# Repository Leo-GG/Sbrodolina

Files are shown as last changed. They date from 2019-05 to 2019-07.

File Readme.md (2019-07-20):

# Sbrodolina

Sbrodolina is a Bioprinter I designed as a consequence of finding myself in possesion of a 3D printer and too much free time.
I started this project with little knowledge about 3D printing, with the intention to educate myself, have fun taking up the challenge of designing a printer from scratch and eventually rejoice seeing it spill some liquids.
She is not the prettiest but I love her all the same.

See it in action in all its glory here: [Sbrodolina spilling water around](https://youtu.be/jMWw5LMnzZg).

Printer Sbrodolina in its current status

Front view Sbrodolina in its current status

## Current status (20/07/2019)

* [First test completed](https://youtu.be/jMWw5LMnzZg)! Extruded water on a piece of cardboard, great success!
* Next goal is to print some more interesting material, but who know when I'll have the time :/
* Few temporary solutions need to be reworked:
  * Endstops are currently held by cable ties. This hurts my eyes every time I see it
  * The syringe pump should be mounted somewhere on the printer
  * Same for the power supply and the Arduino, it is quite messy as it is now
  * The design of the syringe holder on the pump is plainly horrible. I intend to amend this
  * It needs a decent plate to print on

## Design

I designed the printer using aluminium profiles and lead screws on all axis. The idea was to get a robust design. And plenty of wheels and screws everywhere.
Since it is meant to extrude liquids rather than filament, it uses a pipette tip connected to a syringe pump. The syring pump was also 3D printed and has even more design flaws than the body of the printer.

## Control

The printer is controlled like any regular open source 3D printer: I used an Arduino board with a RAMPS shield to control all the motors and endstops. 
I used the MARLIN firmware on the Arduino side and for the time being I use Pronterface to control the printer manually.

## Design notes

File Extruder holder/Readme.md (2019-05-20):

# Extruder holder

This is just a piece meant to hold a pipette or a syring tip. 100% sure this is the ugliest part of the printer. It uses 2 3mm screws with nuts locked in the plastic part to hold the pipette tip in place/
Extruder holder Pipette tip holder

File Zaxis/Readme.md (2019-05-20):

# Z axis

This axis consists of two motors attached to the frame with the same motor mount used in the Y axis. 
Each motor drives a 8mm leadscrew that moves the carriers. The carriers on the motor side are the same as in the Y axis. 
On the front side (opposite to the motors) the carriers are just a flat piece with four holes for 5mm screw nuts (to hold the two sides together) and four holes for 5mm screws to hold the X axis mount. 
Zaxis Z axis motor
The X axis mount is a single piece on each side. I first tried using 4 separated angle pieces, but it was way too wobbly. The current design is not too terrible, so it might stay as it is.

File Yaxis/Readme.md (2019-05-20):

# Y axis

This is the first axis I designed after I managed to make the syringe pump. It consist of a motor mounted on a 20x40 V-shaped aluminum piece and a "carrier" with a leadscrew nut and 4 bearings to move along the frame.
Y axis

The part holding the leadscrew nut are fixed with 3mm screws that are inserted in the corresponding 3mm nuts inserted in the main pieces of the carrier. I was expecting this piece to break apart as soon as the motor started to rotate, but instead they seem to be holding quite well :)

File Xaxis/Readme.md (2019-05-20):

# X axis

This axis consist of a 20x20 V-shaped aluminum frame mounted on the two Z-axis carriers.
axis X axis

The motor is mounted on the 20x20 piece with 2 3D-printed angles that hold the same motor mount used in in all axis. These angles turned out to be rather fragile, I broke them twice when I screwed them too hard against the 20x20 piece.
The carrier for the "extruder" is modified with respect to the other axis to fit the 20mm aluminum piece (the rest are 40mm) and has three 5mm screw holes with holes for the nuts on the back to mount the pipette holder.
axisMotor X axis motor

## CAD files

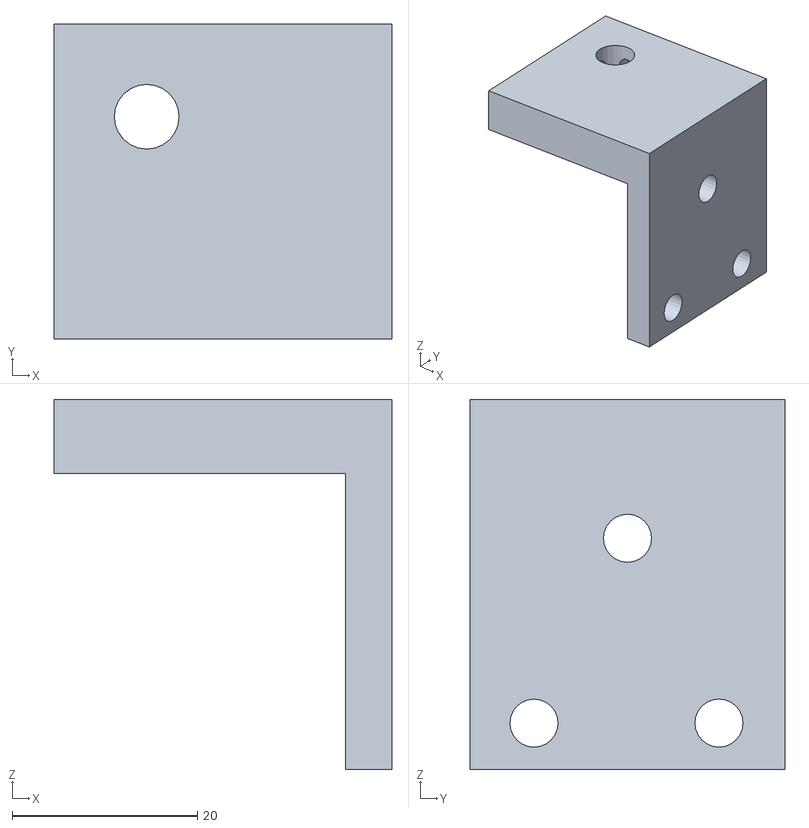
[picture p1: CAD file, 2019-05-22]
Extruder holder/tip_holderDONOTJUDGEMEFORTHIS.stl
36.5 x 34.0 x 40.0

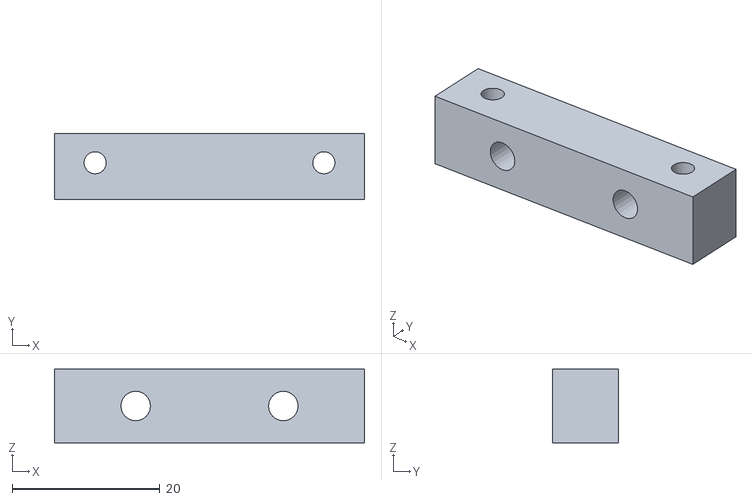
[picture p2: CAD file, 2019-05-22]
Xaxis/motor_mount.stl
42.0 x 9.00 x 10.00

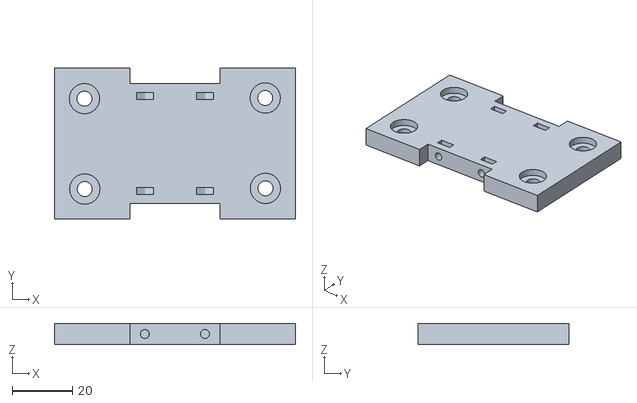
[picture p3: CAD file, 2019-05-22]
Yaxis/carrier_body.stl
80.0 x 50.0 x 7.00

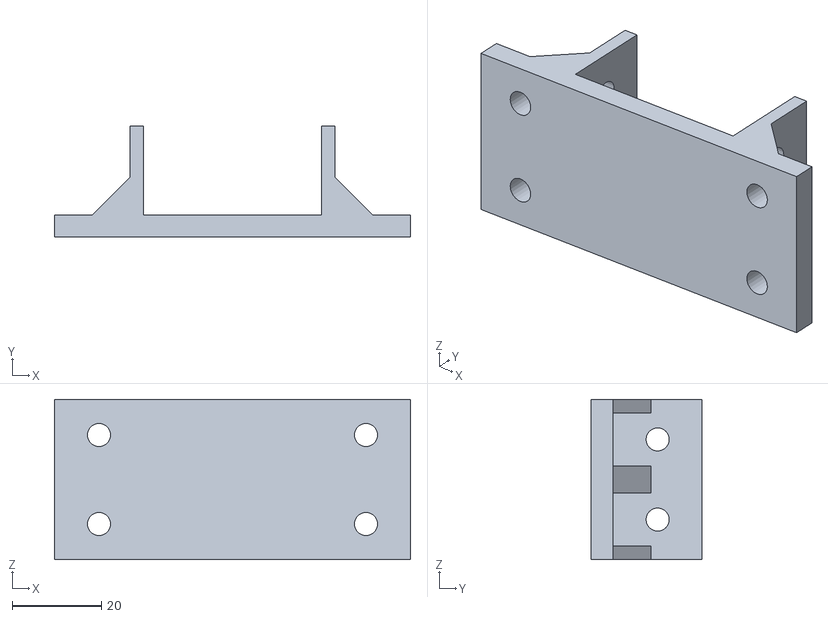
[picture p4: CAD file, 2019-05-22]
Zaxis/Xaxis_rail_mount.stl
80.0 x 25.0 x 36.0

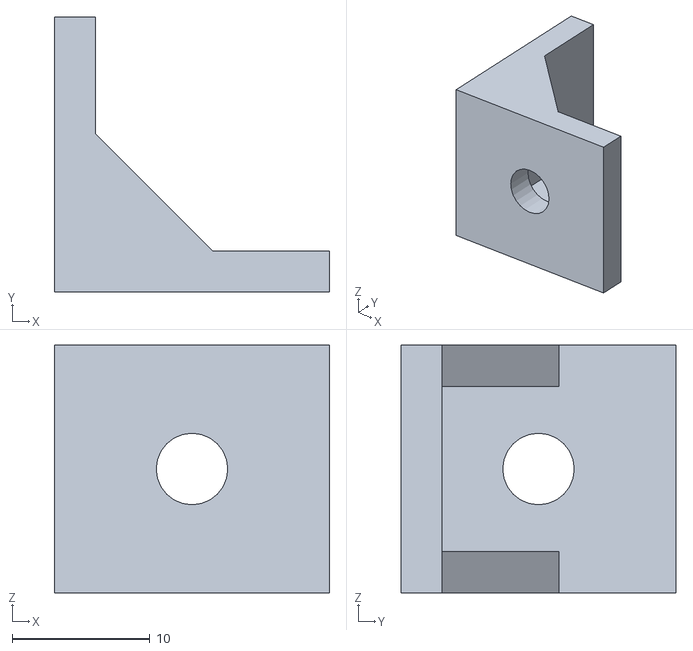
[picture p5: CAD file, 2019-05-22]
Xaxis/motor_mount_angle.stl
20.0 x 20.0 x 18.0

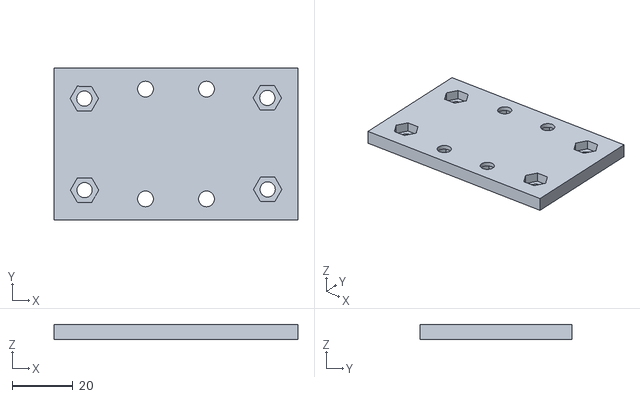
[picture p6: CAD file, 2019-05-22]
Zaxis/carrier_body_front.stl
80.0 x 50.0 x 5.00

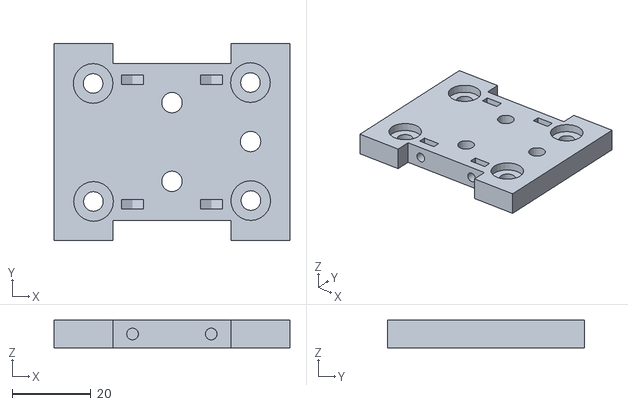
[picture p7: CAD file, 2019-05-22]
Xaxis/carrier_body.stl
60.0 x 50.0 x 7.00

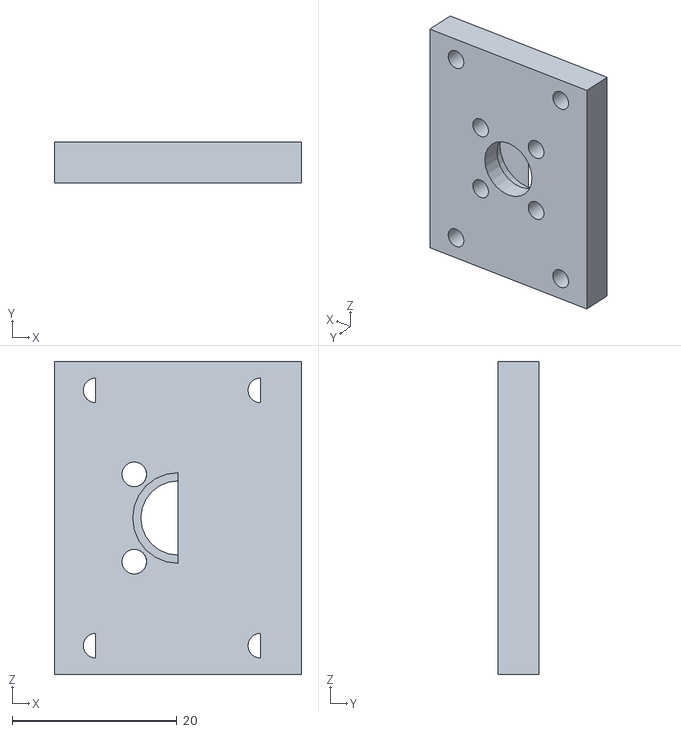
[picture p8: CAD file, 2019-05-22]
Yaxis/carrier_nut_holder.stl
30.0 x 5.00 x 38.0
